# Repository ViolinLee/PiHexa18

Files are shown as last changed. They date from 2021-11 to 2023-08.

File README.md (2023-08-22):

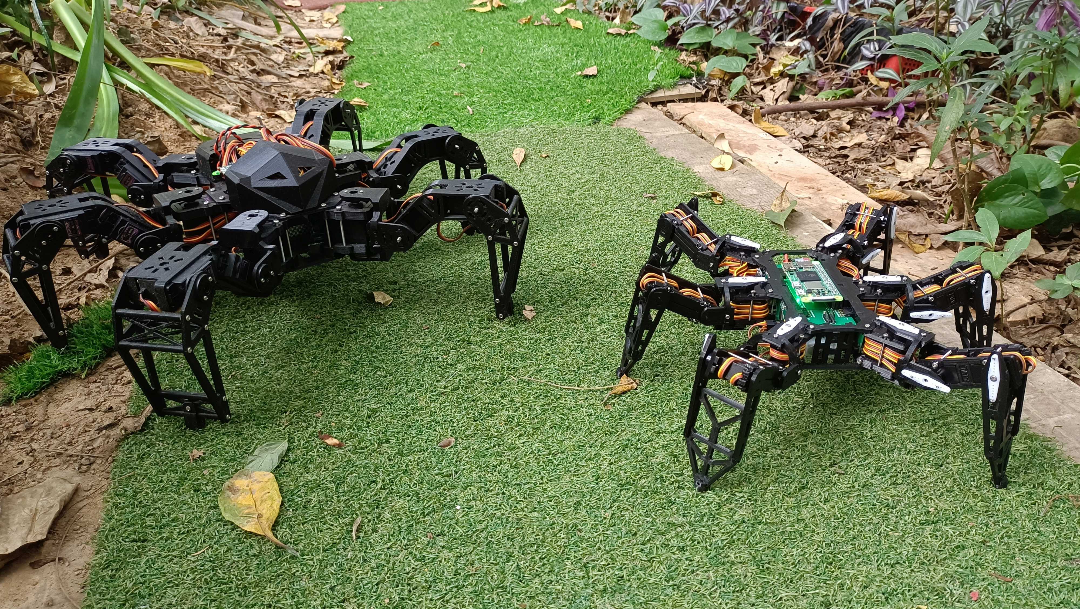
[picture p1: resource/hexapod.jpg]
banner


# PiHexa V1
Hexapod project using Raspberry Pi Zero 2 W and Python.   

## Setup raspberry pi zero 2 W
Suppose the raspberry pi OS is installed:
* WIFI connection configuration through `/etc/wpa_supplicant.conf` file.
* Make raspberry pi (Bluetooth) to be discoverable and paired.
* Enable  I2C Interface for PCA9685 communication.
* Open SSH for debugging.

## Running the main process
Run this script on raspberry-pi.

```
sudo cd ~/PiHexa18/pihexa && python3 running.py
```

RealHexapod

## Animation
Run this script on PC with python packages of matplotlib and pynput installed, then you can switch walking mode of the virtual hexapod by pressing different keys on the your computer keyboard.

```
python pihexa/animate.py
```

Watch this video to learn more: [Plot hexapod walking gait using python script (用Python写一个步态动画展示程序）](https://www.bilibili.com/video/BV1a64y187wR).   

Animation Plot GIF

## Brief introduction
* This project is the python version of the [hexapod-v2-7697](https://github.com/SmallpTsai/hexapod-v2-7697) project written in C++. I modified the size and structure, and redesigned the PCB.
* **Remote control** is done via `BLE` of `Raspberry Zero 2 W`
* It has 6 legs and each has 3 joint. So there are total `18` **Servo motors** (Only support GuoHua `A0090`, JX `PDI1181MG` now and TowerPro `MG92B` in the future)
* NXP `PCA9685` x 2 are used to control these servo motors
* **Power** comes from a `2S Lipo battery (7.4v)`. Also 7 x `mini360 DC-DC` step down voltage regulator are used. One to provide `5V` to Raspberry Pi, The other six to provide `5V` to each legs (1 mini360 serve 3 servo)
* The **body** is 3D printed PLA. I use `Anycubic i3 Mega S`.
* Everything (3D STL, PCB schematic, Python source code) are included in the project under **GPL license**, Happy making!

## Demonstration (Video)
[Bilibili: 开源树莓派Python编程六足机器人功能介绍和运动测试](https://www.bilibili.com/video/BV1Pg411N7Cg/)   
[YouTube: Open Source Hexapod using Raspberry Pi Zero 2 W and Python](https://www.youtube.com/watch?v=hejPARfBBR8&t=43s)

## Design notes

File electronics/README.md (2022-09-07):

# Note
* The version of `AD` is directly exported through the version of `LiChuang` using `"立创EDA"`, and consistency cannot be guaranteed.  
* The 1\*6P and 1\*4P male pin headers on `sub` PCB should be female pin headers.

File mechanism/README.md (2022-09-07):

## Assembly
### Fastener
Name | Spec | Thumbnail | Required | Note
---- | ---- | --------- | -------- | ----
Screw | M2 4mm | 6mm | 8 | Side Wall: 2 x 4
Screw | M2 5mm | 6mm | 36 | Servo Arm: 2 x 18
Screw | M2 6mm | 6mm | 24 | Joint: 4 x 6
Screw | M2 10mm | 10mm | 12 | Thigh Top: 2 x 6
Screw | M2 28mm | 30mm | 36 | Servo: 2 x 18
Screw | M1.6 16mm | 30mm | 6 | Servo: 1 x 6
Screw | M1.2 10mm | 30mm | 12 | Foot: 2 x 6
Nuts | M2 | 6mm | 36 | Servo: 2 x 18
Nuts | M1.6 | 6mm | 12 | Thigh Bottom: 2 x 6
Pin (304) | M4 6mm | pin | 18 | Servo: 1 x 18

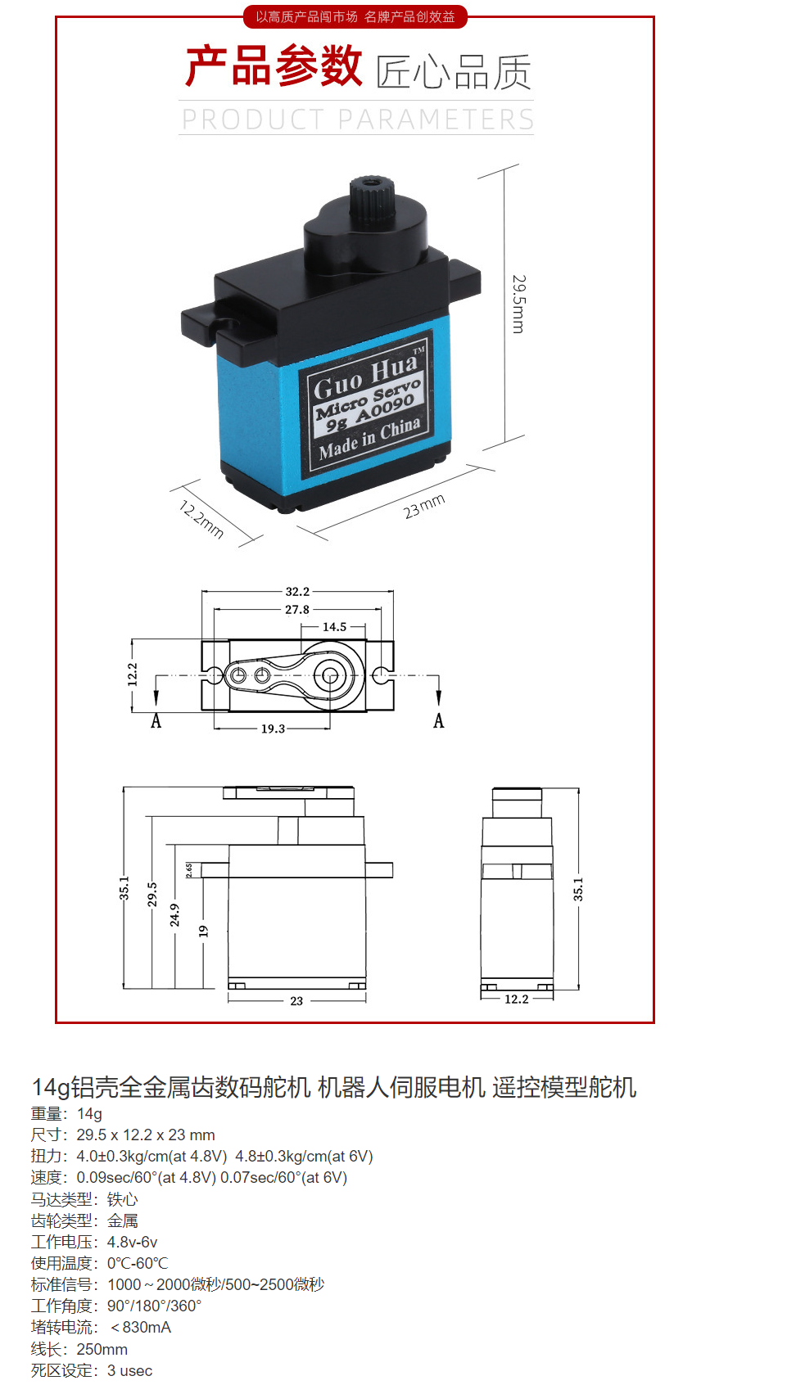
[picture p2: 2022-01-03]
mechanism/Ver.GuoHua-A0090/GuoHua-A0090.png

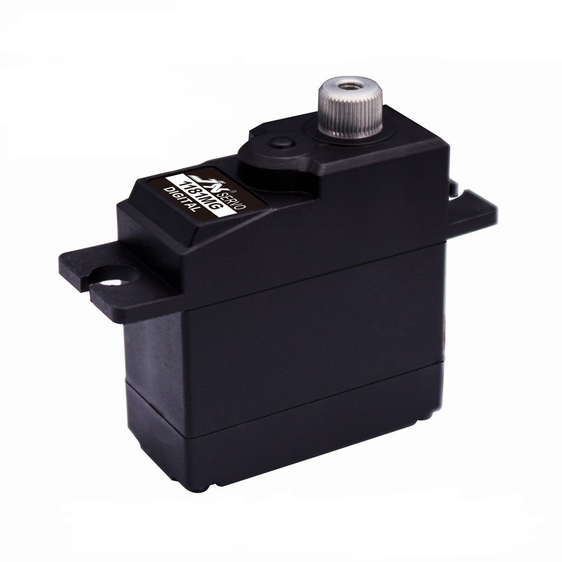
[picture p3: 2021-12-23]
mechanism/Ver.JX-PDI1181MG/servo_dim/PD1181MG.jpg

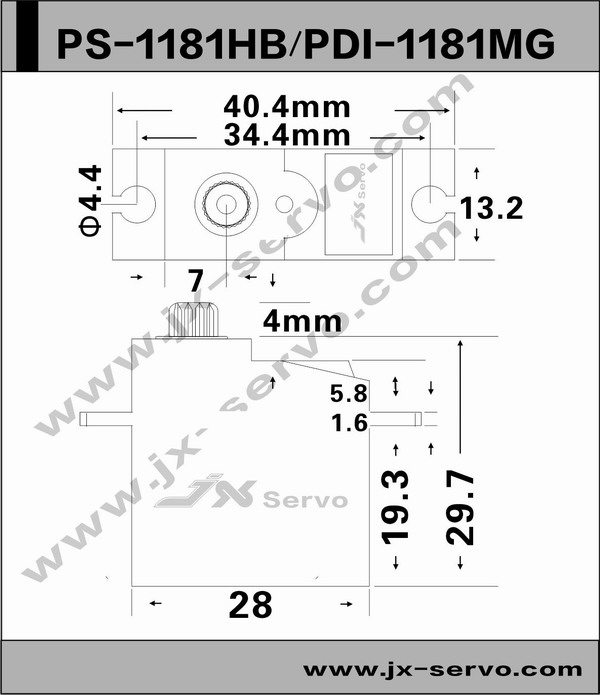
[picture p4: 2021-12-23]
mechanism/Ver.JX-PDI1181MG/servo_dim/dimension.jpg

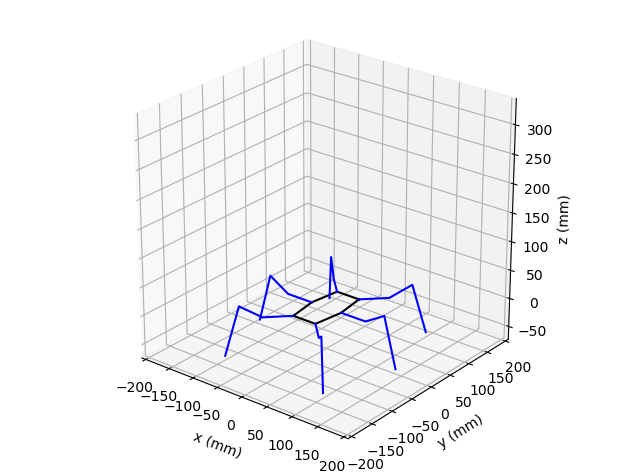
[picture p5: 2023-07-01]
resource/PiHexa18.png

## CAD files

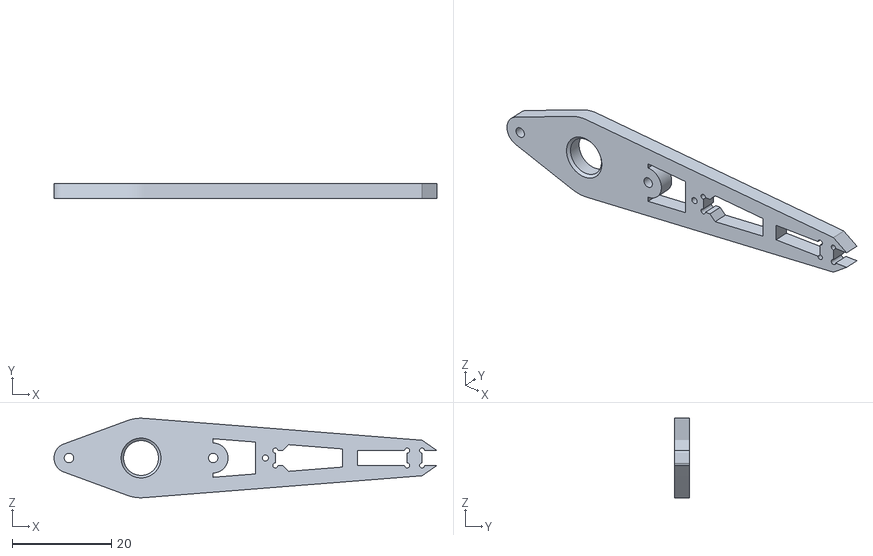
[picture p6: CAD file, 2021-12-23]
mechanism/Ver.GuoHua-A0090/FootTop.STL
77.0 x 3.00 x 16.0

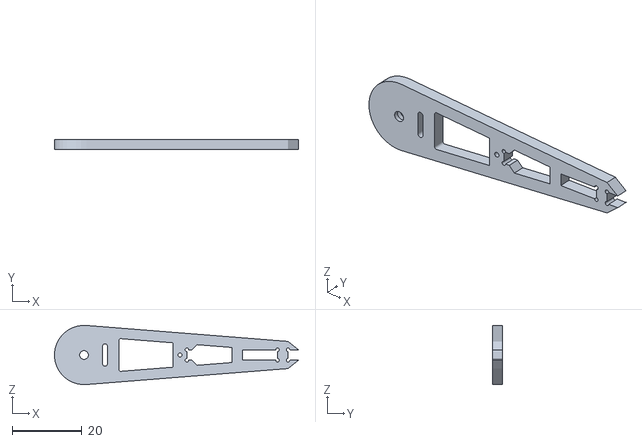
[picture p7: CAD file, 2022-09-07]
mechanism/Ver.JX-PDI1181MG/FootButtom.STL
70.0 x 3.00 x 16.9

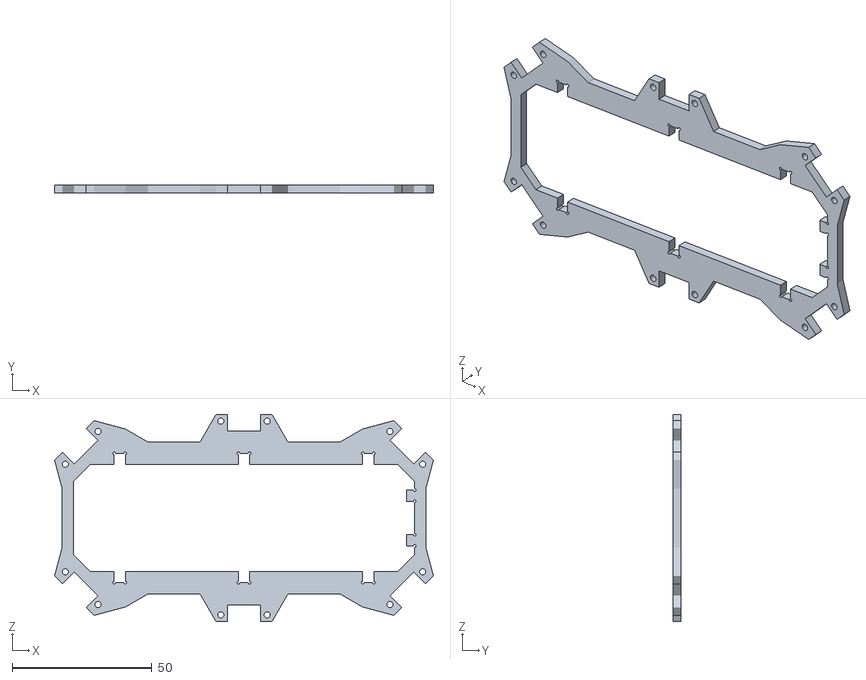
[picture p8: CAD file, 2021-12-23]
mechanism/Ver.GuoHua-A0090/BodyTop.STL
135.8 x 3.00 x 74.3

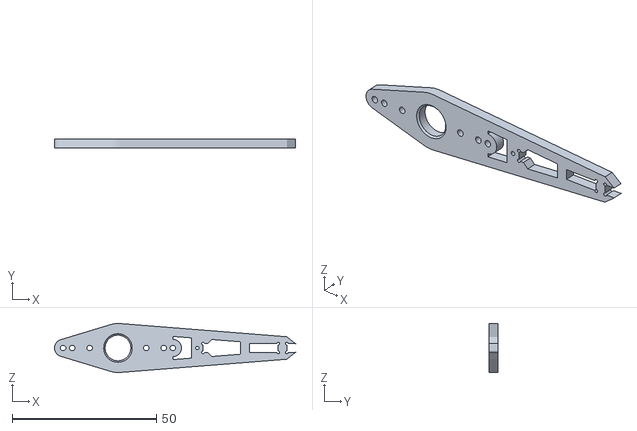
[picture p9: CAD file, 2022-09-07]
mechanism/Ver.JX-PDI1181MG/FootTop.STL
83.5 x 3.00 x 17.0

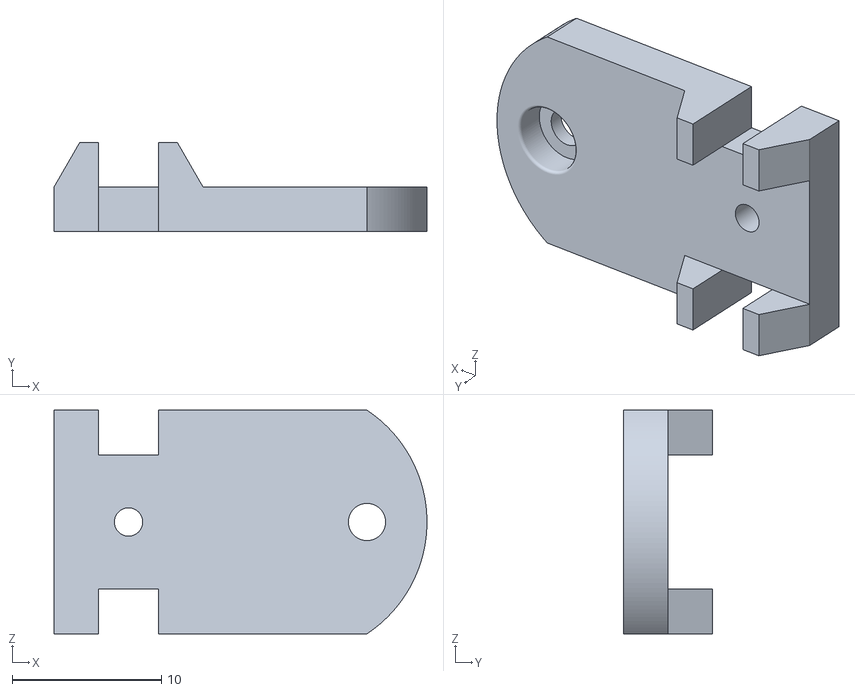
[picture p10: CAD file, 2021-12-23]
mechanism/Ver.GuoHua-A0090/JointDown.STL
25.0 x 6.00 x 15.0

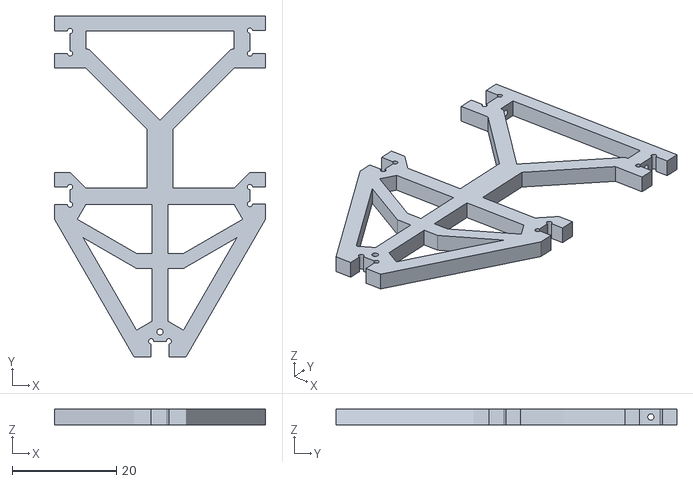
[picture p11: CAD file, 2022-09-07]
mechanism/Ver.JX-PDI1181MG/FootGround.STL
40.5 x 65.4 x 3.00

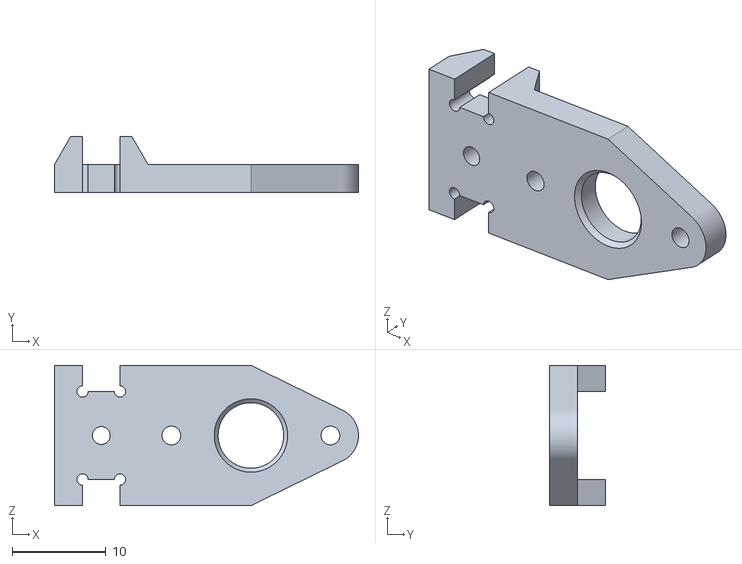
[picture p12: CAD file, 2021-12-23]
mechanism/Ver.GuoHua-A0090/JointTop.STL
32.5 x 6.00 x 15.0

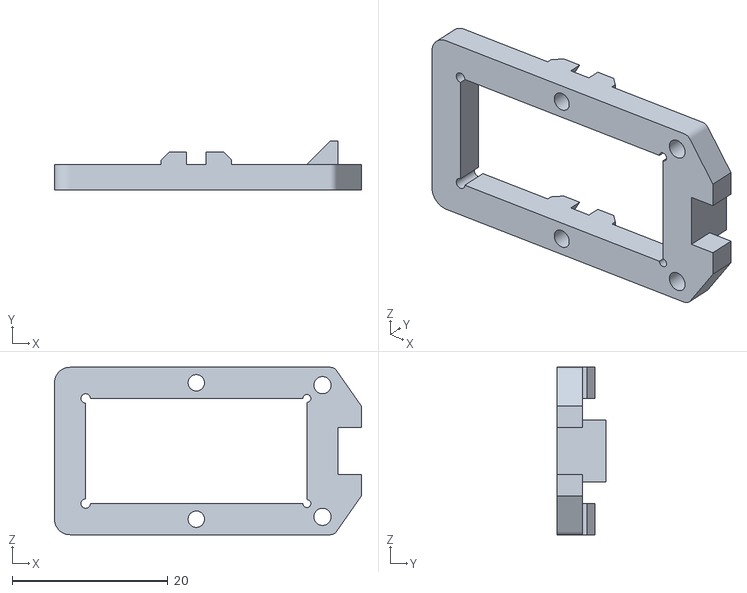
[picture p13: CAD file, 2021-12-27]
mechanism/Ver.JX-PDI1181MG/ThighTop.STL
39.4 x 6.25 x 21.5

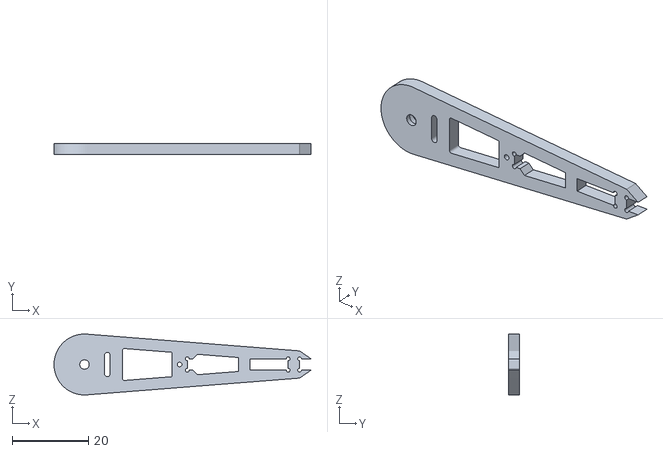
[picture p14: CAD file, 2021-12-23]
mechanism/Ver.GuoHua-A0090/FootButtom.STL
67.5 x 3.00 x 16.0

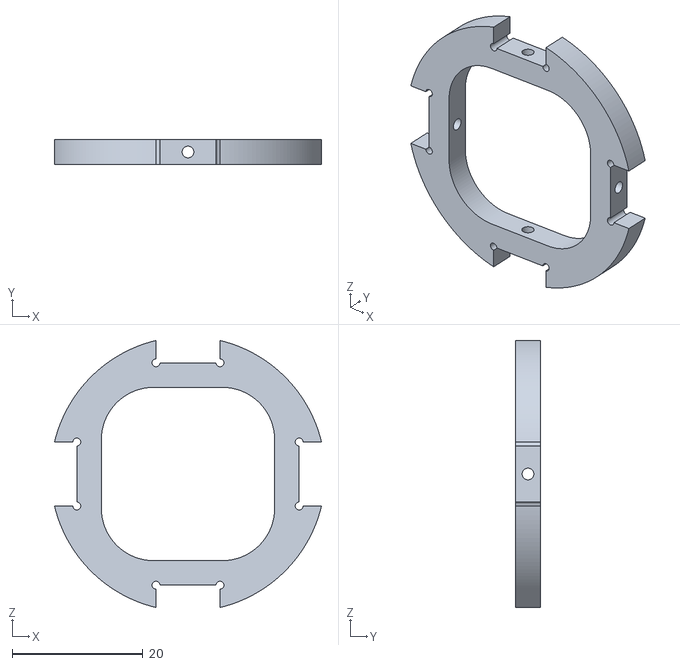
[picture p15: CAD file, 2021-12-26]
mechanism/Ver.JX-PDI1181MG/JointCross.STL
40.8 x 3.90 x 40.8

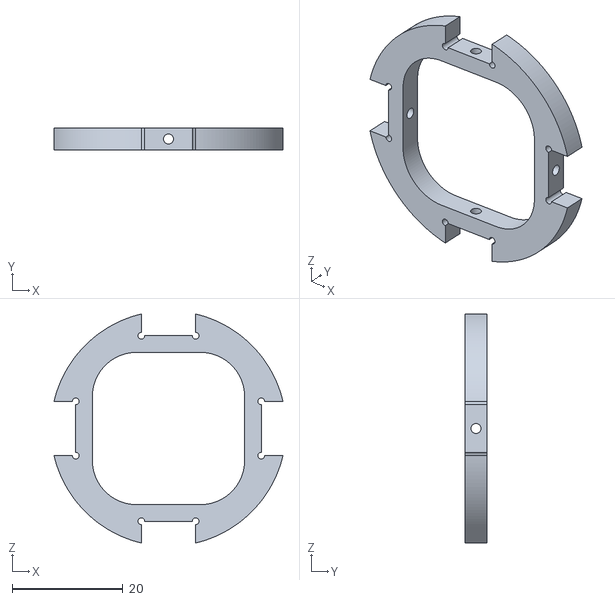
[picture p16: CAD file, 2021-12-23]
mechanism/Ver.GuoHua-A0090/JointCross.STL
41.4 x 3.90 x 41.4

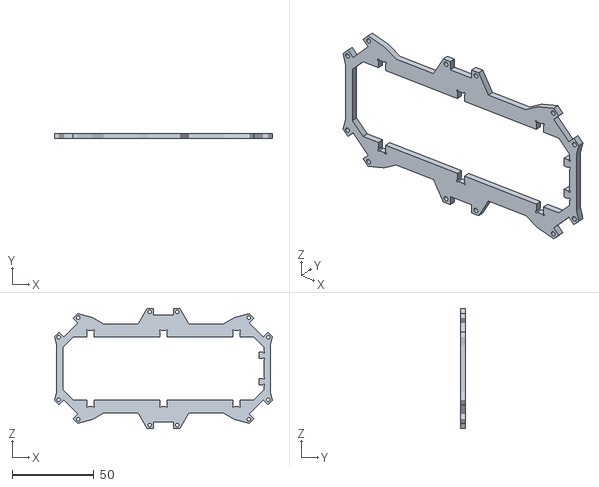
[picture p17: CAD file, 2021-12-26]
mechanism/Ver.JX-PDI1181MG/BodyTop.STL
133.0 x 3.00 x 73.3

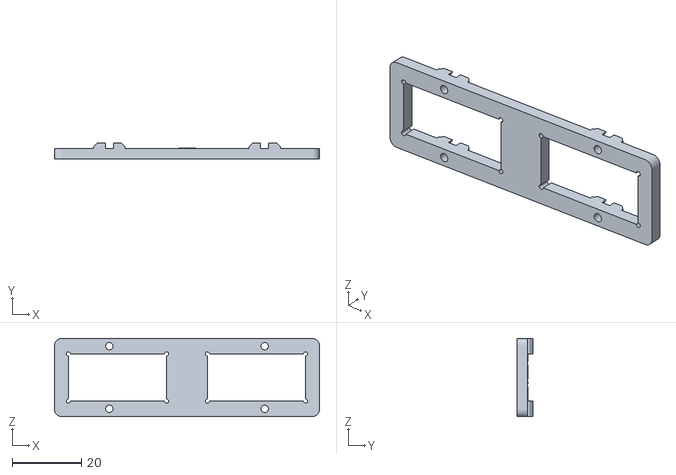
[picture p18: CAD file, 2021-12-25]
mechanism/Ver.JX-PDI1181MG/LegTop.STL
76.4 x 4.60 x 22.5

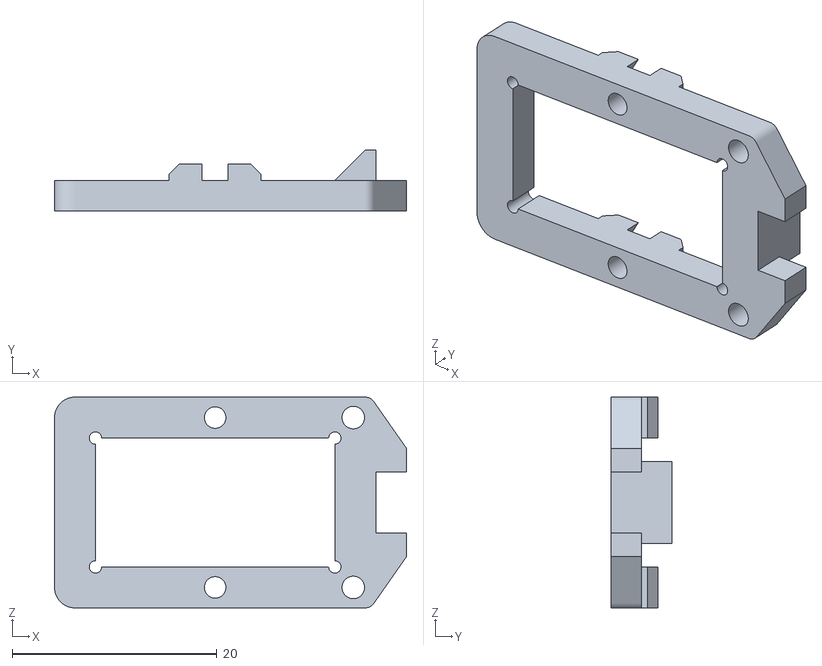
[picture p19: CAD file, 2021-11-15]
mechanism/Ver.GuoHua-A0090/ThighTop.STL
34.4 x 6.00 x 20.6

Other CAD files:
mechanism/Ver.GuoHua-A0090/FootGround.STL
mechanism/Ver.JX-PDI1181MG/ThighBottom.STL
mechanism/Ver.GuoHua-A0090/LegTop.STL
mechanism/Ver.JX-PDI1181MG/JointDown.STL
mechanism/Ver.GuoHua-A0090/LegBottom.STL
mechanism/Ver.GuoHua-A0090/ThighBottom.STL
mechanism/Ver.JX-PDI1181MG/BodyBackWall.STL
mechanism/Ver.JX-PDI1181MG/BodyButtom.STL
mechanism/Ver.JX-PDI1181MG/BodyCenter.STL
mechanism/Ver.JX-PDI1181MG/BodySideWall.STL
mechanism/Ver.JX-PDI1181MG/FootTip.STL
mechanism/Ver.JX-PDI1181MG/JointTop.STL
mechanism/Ver.JX-PDI1181MG/LegBottom.STL

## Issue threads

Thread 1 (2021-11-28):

老板，没看到PCB文件呢

RickWu416, 2021-11-28:

ViolinLee, 2021-11-29:
很快补上

ViolinLee, 2021-11-29:
做下修改就发上来

RickWu416, 2021-11-29:
微雪的树莓派舵机驱动板能直接驱动么

RickWu416, 2021-11-29:
麻烦问下up主，微雪的树莓派舵机驱动板可以直接驱动么

ViolinLee, 2021-11-30:
> 麻烦问下up主，微雪的树莓派舵机驱动板可以直接驱动么

可以的，但是我记得只能驱动16个舵机吧

Mcmullen-Mercer, 2021-12-07:
大佬，pcb能发了吗？

ViolinLee, 2021-12-09:
pcb已发

RickWu416, 2021-12-13:
已下载，感谢up主

Closed 2021-12-09.

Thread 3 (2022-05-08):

关于运行running报错的问题

XionghuiLi, 2022-05-08:
环境搭建和配置都解决了，WIFI可正常连接，蓝牙也已经连接配对，但运行running时会报大量的错，大多关于设备未连接、未发现设备等等，我觉得可能是没把主控板放到驱动板上，然后我把硬件什么的都做好，跑running依旧报跟之前一样的错......

我查询了一些解决方法，并没有起到很好的效果，所以想向您请教

下面是跑running时报的错误：

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

ViolinLee, 2022-05-12:
>

大概率是树莓派蓝牙没有设置好，先保证手机能搜索和配对pi的蓝牙

XionghuiLi, 2022-05-14:
额，手机是可以搜索和配对蓝牙的，
我经过以下尝试：蓝牙关闭running，然后观察报错情况，蓝牙无论关闭与否、连接与否，依旧会报同样的错误。

ViolinLee, 2022-06-03:
> 额，手机是可以搜索和配对蓝牙的， 我经过以下尝试：蓝牙关闭running，然后观察报错情况，蓝牙无论关闭与否、连接与否，依旧会报同样的错误。

配对成功还需要配置才能通讯，可以参照[这篇文章](https://blog.csdn.net/qq_42747705/article/details/116948131)

Closed 2022-07-20.

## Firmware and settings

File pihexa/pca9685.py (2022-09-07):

#!/usr/bin/python

import time
import math
try:
    import smbus
except ModuleNotFoundError:
    pass


# ============================================================================
# Raspi PCA9685 16-Channel PWM Servo Driver
# ============================================================================

class PCA9685:
    # Registers/etc.
    __SUBADR1 = 0x02
    __SUBADR2 = 0x03
    __SUBADR3 = 0x04
    __MODE1 = 0x00
    __PRESCALE = 0xFE
    __LED0_ON_L = 0x06
    __LED0_ON_H = 0x07
    __LED0_OFF_L = 0x08
    __LED0_OFF_H = 0x09
    __ALLLED_ON_L = 0xFA
    __ALLLED_ON_H = 0xFB
    __ALLLED_OFF_L = 0xFC
    __ALLLED_OFF_H = 0xFD

    def __init__(self, address=0x40, debug=False):
        self.bus = smbus.SMBus(1)
        self.address = address
        self.debug = debug
        if (self.debug):
            print("Reseting PCA9685")
        self.write(self.__MODE1, 0x00)

    def write(self, reg, value):
        "Writes an 8-bit value to the specified register/address"
        self.bus.write_byte_data(self.address, reg, value)
        if (self.debug):
            print("I2C: Write 0x%02X to register 0x%02X" % (value, reg))

    def read(self, reg):
        "Read an unsigned byte from the I2C device"
        result = self.bus.read_byte_data(self.address, reg)
        if (self.debug):
            print("I2C: Device 0x%02X returned 0x%02X from reg 0x%02X" % (self.address, result & 0xFF, reg))
        return result

    def setPWMFreq(self, freq):
        "Sets the PWM frequency"
        prescaleval = 25000000.0  # 25MHz
        prescaleval /= 4096.0  # 12-bit
        prescaleval /= float(freq)
        prescaleval -= 1.0
        if (self.debug):
            print("Setting PWM frequency to %d Hz" % freq)
            print("Estimated pre-scale: %d" % prescaleval)
        prescale = math.floor(prescaleval + 0.5)
        if (self.debug):
            print("Final pre-scale: %d" % prescale)

        oldmode = self.read(self.__MODE1)
        newmode = (oldmode & 0x7F) | 0x10  # sleep
        self.write(self.__MODE1, newmode)  # go to sleep
        self.write(self.__PRESCALE, int(math.floor(prescale)))
        self.write(self.__MODE1, oldmode)
        time.sleep(0.005)
        self.write(self.__MODE1, oldmode | 0x80)

    def setPWM(self, channel, on, off):
        "Sets a single PWM channel"
        self.write(self.__LED0_ON_L + 4 * channel, on & 0xFF)
        self.write(self.__LED0_ON_H + 4 * channel, on >> 8)
        self.write(self.__LED0_OFF_L + 4 * channel, off & 0xFF)
        self.write(self.__LED0_OFF_H + 4 * channel, off >> 8)
        if (self.debug):
            print("channel: %d  LED_ON: %d LED_OFF: %d" % (channel, on, off))

    def setServoPulse(self, channel, pulse):
        "Sets the Servo Pulse,The PWM frequency must be 50HZ"
        pulse = pulse * 4096 / 20000  # PWM frequency is 50HZ,the period is 20000us
        self.setPWM(channel, 0, int(pulse))


if __name__ == '__main__':
    pwm = PCA9685(0x40, debug=False)
    pwm.setPWMFreq(50)
    while True:
        # setServoPulse(2,2500)
        for i in range(500, 2500, 10):
            pwm.setServoPulse(0, i)
            time.sleep(0.02)

        for i in range(2500, 500, -10):
            pwm.setServoPulse(0, i)
            time.sleep(0.02)

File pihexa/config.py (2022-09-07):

# -*- coding: utf-8 -*-
from math_utils import *


# mounting position
leg_mount_left_right_x = 34.2  # 29.87  # position in x direction of the middle legs
leg_mount_other_x = 25.14  # 22.41  # position in x direction of the fore and hind legs
leg_mount_other_y = 58.14  # 55.41  # position in y direction of the fore and hind legs
mount_position = ((leg_mount_other_x, leg_mount_other_y, 0),
                  (leg_mount_left_right_x, 0, 0),
                  (leg_mount_other_x, -leg_mount_other_y, 0),
                  (-leg_mount_other_x, -leg_mount_other_y, 0),
                  (-leg_mount_left_right_x, 0, 0),
                  (-leg_mount_other_x, leg_mount_other_y, 0))

# link length
leg_root2joint1 = 23.4  # 19.31(A0090)
leg_joint1_2joint2 = 32.0  # 32.0(A0090)
leg_joint2_2joint3 = 54.51  # 41.8(A0090)
leg_joint3_2tip = 92.91  # 90.05(A0090)

# movement parameters (ms)
movement_interval = 5  # 主程序需要的、考虑舵机响应而加的延迟时间
movement_switch_duration = 150  # 步态路径路径点的间隔（计算上）

# calibration results saved path
calibration_path = "calibration.json"
html_path = 'calibration.html'
with open(html_path) as f:
    html_bytes = f.read().encode()

# default mounting angle
default_angle = (-45, 0, 45, 135, 180, 225)

# angle limitation
angleLimitation = ((-45, 45), (-45, 75), (-60, 60))

# movement constance
standby_z = leg_joint3_2tip * COS15 - leg_joint2_2joint3 * SIN30
left_right_x = leg_mount_left_right_x + leg_root2joint1 + leg_joint1_2joint2 + leg_joint2_2joint3 * COS30 + leg_joint3_2tip * SIN15
other_x = leg_mount_other_x + (
            leg_root2joint1 + leg_joint1_2joint2 + leg_joint2_2joint3 * COS30 + leg_joint3_2tip * SIN15) * COS45
other_y = leg_mount_other_y + (
            leg_root2joint1 + leg_joint1_2joint2 + leg_joint2_2joint3 * COS30 + leg_joint3_2tip * SIN15) * SIN45

# paths way points' locations description
p1_x = other_x
p1_y = other_y
p1_z = -standby_z

p2_x = left_right_x
p2_y = 0
p2_z = -standby_z

p3_x = other_x
p3_y = -other_y
p3_z = -standby_z

p4_x = -other_x
p4_y = -other_y
p4_z = -standby_z

p5_x = -left_right_x
p5_y = 0
p5_z = -standby_z

p6_x = -other_x
p6_y = other_y
p6_z = -standby_z

# for paths generation
default_position = ((other_x, other_y, -standby_z),
                    (left_right_x, 0, -standby_z),
                    (other_x, -other_y, -standby_z),
                    (-other_x, -other_y, -standby_z),
                    (-left_right_x, 0, -standby_z),
                    (-other_x, other_y, -standby_z))

# for paths locations calculation of real robot
k_standby = [(p1_x, p1_y, p1_z),
             (p2_x, p2_y, p2_z),
             (p3_x, p3_y, p3_z),
             (p4_x, p4_y, p4_z),
             (p5_x, p5_y, p5_z),
             (p6_x, p6_y, p6_z)]
standby_entries = (0, )
standby_entries_count = 1  # Number of elements of variable standby_entries

# servo specification
pulse_min = 900  # 544 (A0090) 900(1181)
pulse_max = 2100  # 2400(A0090) 2100(1181)

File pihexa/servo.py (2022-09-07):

# -*- coding: utf-8 -*-

from pca9685 import PCA9685
# from numpy import interp


class Servo(object):
    def __init__(self, left_address=0x40, right_address=0x41, pulse_min=544, pulse_max=2400, freq=50):
        self.offset = [[0, 0, 0]] * 6
        self.pwm_left = PCA9685(left_address)
        self.pwm_right = PCA9685(right_address)
        self.pulse_min = pulse_min
        self.pulse_max = pulse_max
        self.pulse_middle = (self.pulse_min + self.pulse_max) / 2

        # Set pwm frequency
        self.pwm_left.setPWMFreq(freq)
        self.pwm_right.setPWMFreq(freq)

    def angle2pulse(self, km_angle, reverse):
        # return interp(correct * km_angle, [-90, 90], [pulse_min, pulse_max])  # 注意运动学定义的0°对应舵机90°位置
        return (self.pulse_min + self.pulse_max) / 2 + reverse * km_angle * ((self.pulse_max - self.pulse_min) / 180)

    def set_offset(self, offset):
        self.offset = offset

    def set_angle(self, leg_index, part_index, km_angle):
        # switch left, right pwm
        if leg_index == 0:
            pwm_index = 5 + part_index
            pwm = self.pwm_right
        elif leg_index == 1:
            pwm_index = 2 + part_index
            pwm = self.pwm_right
        elif leg_index == 2:
            pwm_index = 8 + part_index
            pwm = self.pwm_right
        elif leg_index == 3:
            pwm_index = 8 + part_index
            pwm = self.pwm_left
        elif leg_index == 4:
            pwm_index = 2 + part_index
            pwm = self.pwm_left
        elif leg_index == 5:
            pwm_index = 5 + part_index
            pwm = self.pwm_left
        else:
            raise ValueError

        km_angle_corrected = km_angle + self.offset[leg_index][part_index]
        inverse = -1 if part_index == 1 else 1
        pulse = self.angle2pulse(km_angle_corrected, inverse)
        pwm.setServoPulse(pwm_index, pulse)


if __name__ == '__main__':
    from time import sleep

    servo = Servo()
    while True:
        for angle in range(-90, 91):
            for leg_i in range(6):
                for part_j in range(3):
                    servo.set_angle(leg_i, part_j, angle)
            sleep(0.02)
        for angle in range(90, -91, -1):
            for leg_i in range(6):
                for part_j in range(3):
                    servo.set_angle(leg_i, part_j, angle)
            sleep(0.02)

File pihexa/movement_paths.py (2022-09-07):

"""This file is generated, dont directly modify content..."""

from config import *

forward_paths = [[(p1_x + 0.00, p1_y + 0.00, p1_z + 25.00), (p2_x + 0.00, p2_y + 0.00, p2_z + 0.00), (p3_x + 0.00, p3_y + 0.00, p3_z + 25.00), (p4_x + 0.00, p4_y + 0.00, p4_z + 0.00), (p5_x + 0.00, p5_y + 0.00, p5_z + 25.00), (p6_x + 0.00, p6_y + 0.00, p6_z + 0.00)],
                 [(p1_x + 0.00, p1_y + 7.73, p1_z + 23.78), (p2_x + 0.00, p2_y + -5.00, p2_z + 0.00), (p3_x + 0.00, p3_y + 7.73, p3_z + 23.78), (p4_x + 0.00, p4_y + -5.00, p4_z + 0.00), (p5_x + 0.00, p5_y + 7.73, p5_z + 23.78), (p6_x + 0.00, p6_y + -5.00, p6_z + 0.00)],
                 [(p1_x + 0.00, p1_y + 14.69, p1_z + 20.23), (p2_x + 0.00, p2_y + -10.00, p2_z + 0.00), (p3_x + 0.00, p3_y + 14.69, p3_z + 20.23), (p4_x + 0.00, p4_y + -10.00, p4_z + 0.00), (p5_x + 0.00, p5_y + 14.69, p5_z + 20.23), (p6_x + 0.00, p6_y + -10.00, p6_z + 0.00)],
                 [(p1_x + 0.00, p1_y + 20.23, p1_z + 14.69), (p2_x + 0.00, p2_y + -15.00, p2_z + 0.00), (p3_x + 0.00, p3_y + 20.23, p3_z + 14.69), (p4_x + 0.00, p4_y + -15.00, p4_z + 0.00), (p5_x + 0.00, p5_y + 20.23, p5_z + 14.69), (p6_x + 0.00, p6_y + -15.00, p6_z + 0.00)],
                 [(p1_x + 0.00, p1_y + 23.78, p1_z + 7.73), (p2_x + 0.00, p2_y + -20.00, p2_z + 0.00), (p3_x + 0.00, p3_y + 23.78, p3_z + 7.73), (p4_x + 0.00, p4_y + -20.00, p4_z + 0.00), (p5_x + 0.00, p5_y + 23.78, p5_z + 7.73), (p6_x + 0.00, p6_y + -20.00, p6_z + 0.00)],
                 [(p1_x + 0.00, p1_y + 25.00, p1_z + 0.00), (p2_x + 0.00, p2_y + -25.00, p2_z + 0.00), (p3_x + 0.00, p3_y + 25.00, p3_z + 0.00), (p4_x + 0.00, p4_y + -25.00, p4_z + 0.00), (p5_x + 0.00, p5_y + 25.00, p5_z + 0.00), (p6_x + 0.00, p6_y + -25.00, p6_z + 0.00)],
                 [(p1_x + 0.00, p1_y + 20.00, p1_z + 0.00), (p2_x + 0.00, p2_y + -23.78, p2_z + 7.73), (p3_x + 0.00, p3_y + 20.00, p3_z + 0.00), (p4_x + 0.00, p4_y + -23.78, p4_z + 7.73), (p5_x + 0.00, p5_y + 20.00, p5_z + 0.00), (p6_x + 0.00, p6_y + -23.78, p6_z + 7.73)],
                 [(p1_x + 0.00, p1_y + 15.00, p1_z + 0.00), (p2_x + 0.00, p2_y + -20.23, p2_z + 14.69), (p3_x + 0.00, p3_y + 15.00, p3_z + 0.00), (p4_x + 0.00, p4_y + -20.23, p4_z + 14.69), (p5_x + 0.00, p5_y + 15.00, p5_z + 0.00), (p6_x + 0.00, p6_y + -20.23, p6_z + 14.69)],
                 [(p1_x + 0.00, p1_y + 10.00, p1_z + 0.00), (p2_x + 0.00, p2_y + -14.69, p2_z + 20.23), (p3_x + 0.00, p3_y + 10.00, p3_z + 0.00), (p4_x + 0.00, p4_y + -14.69, p4_z + 20.23), (p5_x + 0.00, p5_y + 10.00, p5_z + 0.00), (p6_x + 0.00, p6_y + -14.69, p6_z + 20.23)],
                 [(p1_x + 0.00, p1_y + 5.00, p1_z + 0.00), (p2_x + 0.00, p2_y + -7.73, p2_z + 23.78), (p3_x + 0.00, p3_y + 5.00, p3_z + 0.00), (p4_x + 0.00, p4_y + -7.73, p4_z + 23.78), (p5_x + 0.00, p5_y + 5.00, p5_z + 0.00), (p6_x + 0.00, p6_y + -7.73, p6_z + 23.78)],
                 [(p1_x + 0.00, p1_y + 0.00, p1_z + 0.00), (p2_x + 0.00, p2_y + 0.00, p2_z + 25.00), (p3_x + 0.00, p3_y + 0.00, p3_z + 0.00), (p4_x + 0.00, p4_y + 0.00, p4_z + 25.00), (p5_x + 0.00, p5_y + 0.00, p5_z + 0.00), (p6_x + 0.00, p6_y + 0.00, p6_z + 25.00)],
                 [(p1_x + 0.00, p1_y + -5.00, p1_z + 0.00), (p2_x + 0.00, p2_y + 7.73, p2_z + 23.78), (p3_x + 0.00, p3_y + -5.00, p3_z + 0.00), (p4_x + 0.00, p4_y + 7.73, p4_z + 23.78), (p5_x + 0.00, p5_y + -5.00, p5_z + 0.00), (p6_x + 0.00, p6_y + 7.73, p6_z + 23.78)],
                 [(p1_x + 0.00, p1_y + -10.00, p1_z + 0.00), (p2_x + 0.00, p2_y + 14.69, p2_z + 20.23), (p3_x + 0.00, p3_y + -10.00, p3_z + 0.00), (p4_x + 0.00, p4_y + 14.69, p4_z + 20.23), (p5_x + 0.00, p5_y + -10.00, p5_z + 0.00), (p6_x + 0.00, p6_y + 14.69, p6_z + 20.23)],
                 [(p1_x + 0.00, p1_y + -15.00, p1_z + 0.00), (p2_x + 0.00, p2_y + 20.23, p2_z + 14.69), (p3_x + 0.00, p3_y + -15.00, p3_z + 0.00), (p4_x + 0.00, p4_y + 20.23, p4_z + 14.69), (p5_x + 0.00, p5_y + -15.00, p5_z + 0.00), (p6_x + 0.00, p6_y + 20.23, p6_z + 14.69)],
                 [(p1_x + 0.00, p1_y + -20.00, p1_z + 0.00), (p2_x + 0.00, p2_y + 23.78, p2_z + 7.73), (p3_x + 0.00, p3_y + -20.00, p3_z + 0.00), (p4_x + 0.00, p4_y + 23.78, p4_z + 7.73), (p5_x + 0.00, p5_y + -20.00, p5_z + 0.00), (p6_x + 0.00, p6_y + 23.78, p6_z + 7.73)],
                 [(p1_x + 0.00, p1_y + -25.00, p1_z + 0.00), (p2_x + 0.00, p2_y + 25.00, p2_z + 0.00), (p3_x + 0.00, p3_y + -25.00, p3_z + 0.00), (p4_x + 0.00, p4_y + 25.00, p4_z + 0.00), (p5_x + 0.00, p5_y + -25.00, p5_z + 0.00), (p6_x + 0.00, p6_y + 25.00, p6_z + 0.00)],
                 [(p1_x + 0.00, p1_y + -23.78, p1_z + 7.73), (p2_x + 0.00, p2_y + 20.00, p2_z + 0.00), (p3_x + 0.00, p3_y + -23.78, p3_z + 7.73), (p4_x + 0.00, p4_y + 20.00, p4_z + 0.00), (p5_x + 0.00, p5_y + -23.78, p5_z + 7.73), (p6_x + 0.00, p6_y + 20.00, p6_z + 0.00)],
                 [(p1_x + 0.00, p1_y + -20.23, p1_z + 14.69), (p2_x + 0.00, p2_y + 15.00, p2_z + 0.00), (p3_x + 0.00, p3_y + -20.23, p3_z + 14.69), (p4_x + 0.00, p4_y + 15.00, p4_z + 0.00), (p5_x + 0.00, p5_y + -20.23, p5_z + 14.69), (p6_x + 0.00, p6_y + 15.00, p6_z + 0.00)],
                 [(p1_x + 0.00, p1_y + -14.69, p1_z + 20.23), (p2_x + 0.00, p2_y + 10.00, p2_z + 0.00), (p3_x + 0.00, p3_y + -14.69, p3_z + 20.23), (p4_x + 0.00, p4_y + 10.00, p4_z + 0.00), (p5_x + 0.00, p5_y + -14.69, p5_z + 20.23), (p6_x + 0.00, p6_y + 10.00, p6_z + 0.00)],
                 [(p1_x + 0.00, p1_y + -7.73, p1_z + 23.78), (p2_x + 0.00, p2_y + 5.00, p2_z + 0.00), (p3_x + 0.00, p3_y + -7.73, p3_z + 23.78), (p4_x + 0.00, p4_y + 5.00, p4_z + 0.00), (p5_x + 0.00, p5_y + -7.73, p5_z + 23.78), (p6_x + 0.00, p6_y + 5.00, p6_z + 0.00)]]
forward_length = 20
forward_duration = 20
forward_entries = (0, 10)
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

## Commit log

2020-07-16 add leg class
2020-07-17 add leg moving func
2020-07-20 servo class first commit
2021-09-27 add kinematics... scripts
2021-09-29 modify leg class
2021-11-06 edit servo interface
2021-11-15 add mechanism stl
    [BodyBackWall.STL, BodyButtom.STL, BodyCenter.STL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]
2021-11-16 add web calibration
2021-11-16 add servo test case
2021-11-16 modify servo test case
2021-11-17 add calibration html
2021-11-17 global servo
2021-11-18 init servo on hexapod class
2021-11-19 fix calibrator bug
2021-11-20 add hexapod and leg base class
2021-11-20 fix standby mode bug
    [config.py, movement.py, remote.py]
2021-11-26 add setup flow
2021-11-30 add kinematic gait tutorial
2021-12-09 add pcb files
    [PCB_PiHexaSub_2021-12-09.pcbdoc, PCB_PiHexa_2021-12-09.pcbdoc, main_2021-12-09.schdoc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]
2021-12-09 add pcb readme
2021-12-09 modify pcb readme
2021-12-22 modity stl
    [BodyBackWall.STL, BodyButtom.STL]
2021-12-23 modify foot design
    [BodyBackWall.STL, BodyButtom.STL, BodyCenter.STL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]
2021-12-23 finish a0090 version
    [BodyCenter.STL, BodySideWall.STL, BodyTop.STL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]
2021-12-25 add ver.1181 foot stl
    [FootButtom.STL, FootGround.STL, FootTop.STL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]
2021-12-26 add ver.1181 body stl
    [BodyBackWall.STL, BodyButtom.STL, BodyCenter.STL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]
2021-12-27 add thigh top stl
    [ThighTop.STL]
2022-01-01 add assembly readme
2022-01-01 update foot ground stl
    [FootGround.STL]
2022-01-02 update foot bottom stl
    [FootButtom.STL]
2022-01-03 add 1181 servo specification
2022-09-07 modify movement_table
    [FootButtom.STL, FootGround.STL, FootTop.STL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]
2023-12-04 添加web-api操控支持
2023-12-13 fix:WebRemote类抛弃mode构造参数
